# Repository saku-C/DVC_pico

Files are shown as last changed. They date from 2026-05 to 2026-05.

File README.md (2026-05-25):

# DVC-PICO v2 Controller & Analyzer

RP2040（Raspberry Pi Pico / Pico 2）をベースにした、多機能なDMX-512コントローラーおよびオシロスコープ・アナライザープロジェクトです。
ハードウェア（KiCad設計データ）とファームウェア（Arduinoスケッチ）が一体となって管理されています。

内部構造
https://qiita.com/kurumi18891/private/b40f511b77fc0b5f25af

操作マニュアル
https://qiita.com/kurumi18891/private/ef590465823563e47984

---

## 📂 フォルダ構成

```
DVC_pico2_1/ (リポジトリルート)
├── DVC_pico2_1.ino        # メインファームウェア (Arduinoスケッチ)
├── .gitignore             # Git除外設定ファイル
├── README.md              # 本ドキュメント
├── antigra_DVCpico/       # 補助フォルダ
└── kicad_DVC_pico/        # ハードウェア設計データ
    └── DVC-picov2/        # KiCad v2 回路図・基板アートワーク
        ├── DVC-picov2.kicad_pcb # 基板レイアウト
        ├── DVC-picov2.kicad_pro # KiCad プロジェクトファイル
        ├── DVC-picov2.kicad_sch # 回路図
        └── ...
```

---

## ✨ 主な機能

1. **多彩な通信モード（6チャネル拡張）**
   * **Monitor Only**: 送受信データの監視
   * **Read DMX -> SD**: 受信したDMXデータをCSV形式でSDカードにリアルタイム録画
   * **Write DMX <- SD**: SDカードに記録されたCSVファイルを再生し、DMX信号を出力
   * **Read DMX -> USB**: DMXデータをUSBシリアル経由でPCに送信
   * **Write DMX <- USB**: USB経由で受信したコマンドに基づいてDMX信号を出力
   * **Manual Controller**: 7つの操作キーを使用した、手動でのDMXチャンネル出力制御
2. **5つの画面表示モード**
   * **Waveform Monitor**: DMX各チャネルの値を波形（オシロスコープスタイル）でビジュアル表示
   * **Table Monitor**: DMX 512チャネルの数値をグリッド状に一覧表示
   * **Dashboard**: システムの稼働ステータスや通信統計、診断結果をサマリー表示
   * **Fixture Inspector**: 灯体（フィクスチャ）のチャンネル定義と設定値の確認
   * **Multi-Light Monitor**: 10灯のインテリジェントライトの個別モニターおよびプロファイル調整
3. **対話型フィクスチャ（灯体）エディター**
   * 接続されたDMX機器のチャンネル数や各チャンネルの役割（Dimmer, Red, Green, Blue, Strobe等）を本体キーで自由に変更・カスタム可能
4. **永続データ保存（EEPROMエミュレーション）**
   * 設定したフィクスチャのプロファイルデータをRP2040の内蔵フラッシュメモリに自動で保存・復元

---

## 🛠️ ハードウェア仕様とピン配置

### 主要コンポーネント
* **MCU**: Raspberry Pi Pico / Pico 2 (RP2040 / RP2350)
* **ディスプレイ**: 1.8インチ ST7735 TFTカラー液晶 (160x128)
* **外部ストレージ**: MicroSDカードスロット（ソフトウェアSPI動作）
* **DMXインターフェース**: MAX485トランシーバー搭載

### ピン割り当て (RP2040)
* **TFT ディスプレイ**:
  * `CS`  -> GPIO 22
  * `RST` -> GPIO 21
  * `DC`  -> GPIO 20
  * `LED` -> GPIO 17
* **SDカード (SoftSPI)**:
  * `SCK`  -> GPIO 10
  * `MISO` -> GPIO 11
  * `MOSI` -> GPIO 12
  * `CS`   -> GPIO 13
* **DMX**:
  * `TX`    -> GPIO 0
  * `RX`    -> GPIO 1
  * `RE_DE` -> GPIO 2
* **操作ボタン (Active LOW)**:
  * `SETTING` -> GPIO 9
  * `UP`      -> GPIO 8
  * `DOWN`    -> GPIO 4
  * `LEFT`    -> GPIO 6
  * `RIGHT`   -> GPIO 7
  * `ENTER`   -> GPIO 5
  * `BACK`    -> GPIO 3

---

## ⚙️ 開発環境と依存ライブラリ

ファームウェアをコンパイルするには、Arduino IDEに以下のライブラリを追加してください：

* **Adafruit_GFX** (ディスプレイ描画用)
* **Adafruit_ST7735** (ST7735制御用)
* **SdFat** (SDカードの高速読み書き用)
* **Pico DMX (DmxInput / DmxOutput)** (Earle Philhower版コアのDMX送受信サポート)

*※ボードマネージャーは「Raspberry Pi Pico/RP2040 (Earle Philhower版)」の使用を想定しています。*

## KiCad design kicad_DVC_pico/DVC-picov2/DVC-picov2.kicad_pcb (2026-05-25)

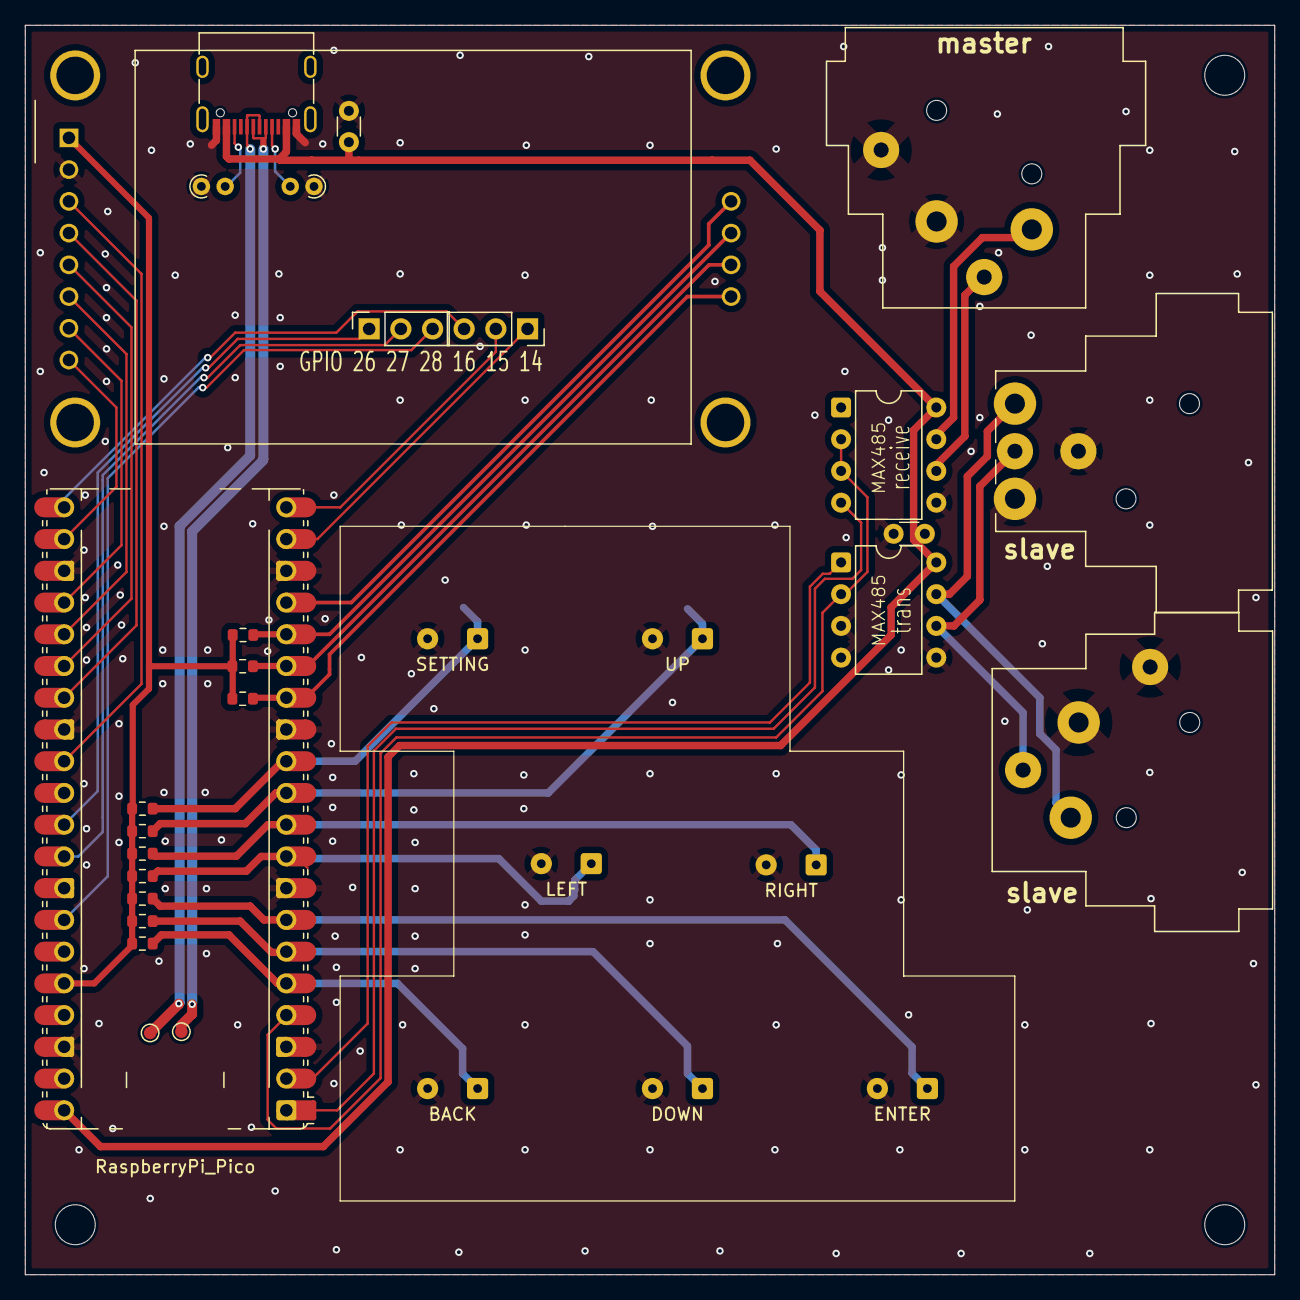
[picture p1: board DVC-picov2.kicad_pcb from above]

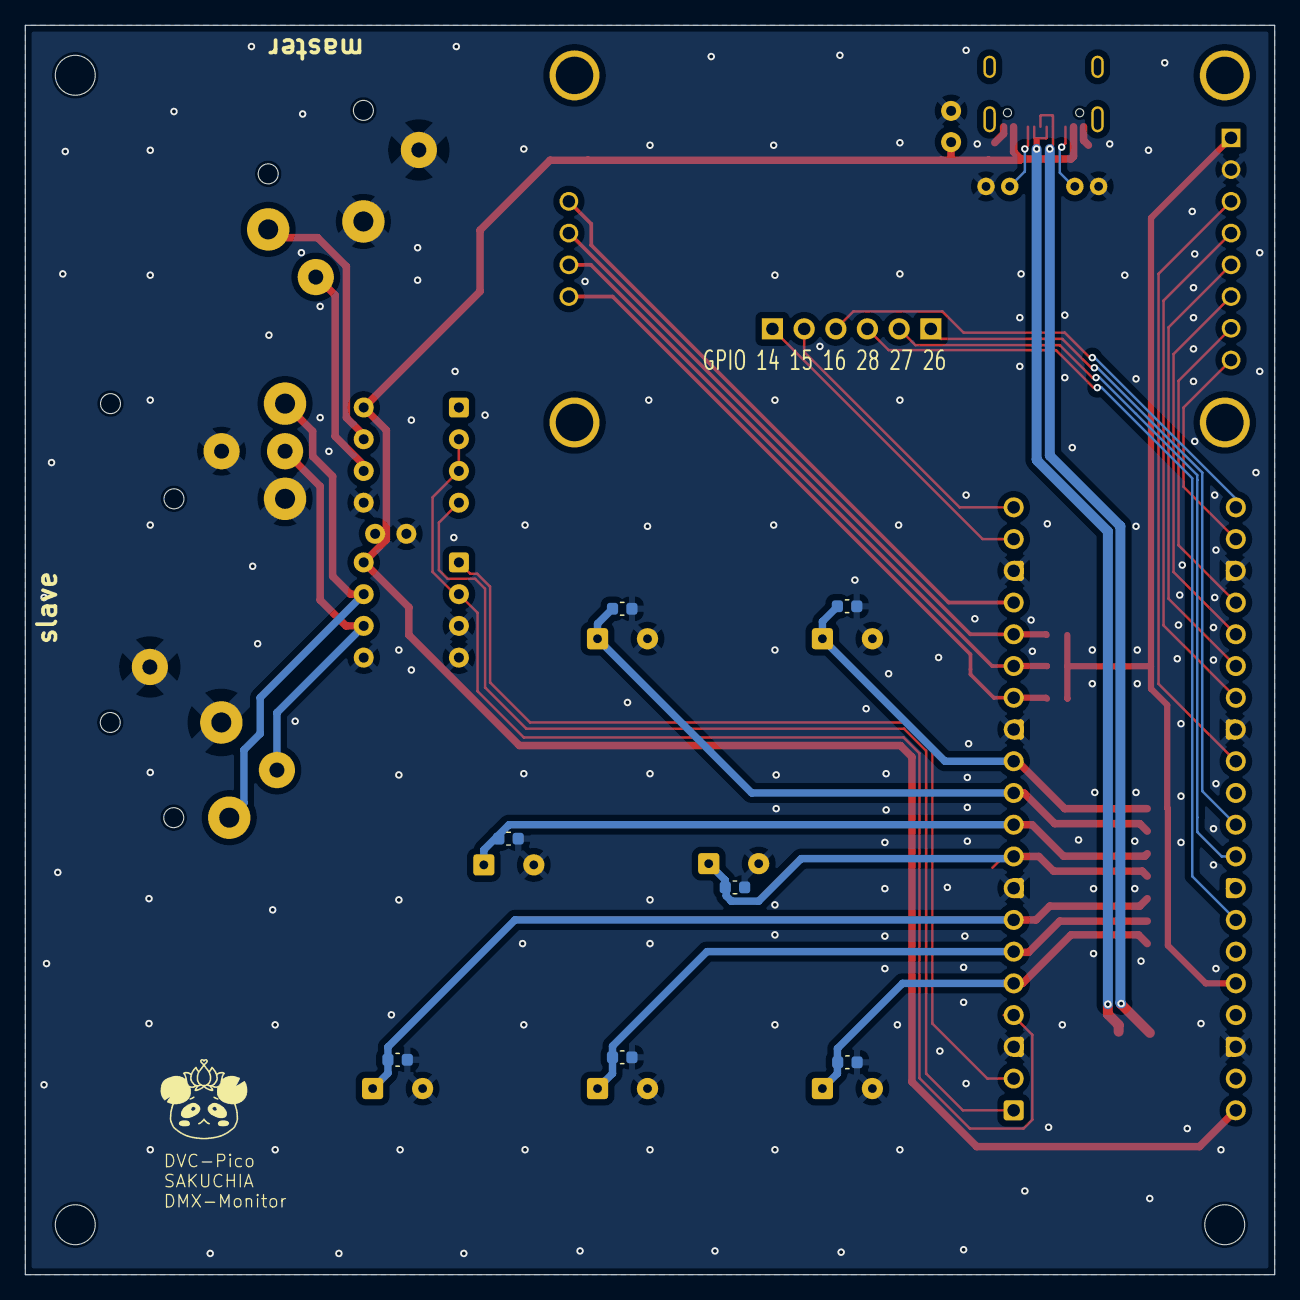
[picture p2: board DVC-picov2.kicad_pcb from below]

Board: 2 copper layers, 100.0 x 100.0 mm, 41 parts (7 on the bottom side), 37 nets.

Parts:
A1: RaspberryPi_Pico; RaspberryPi_Pico_Common_Unspecified
BACK: SW_Push; SolderWire-0.15sqmm_1x02_P4mm_D0.5mm_OD1.5mm
C1, C2: C; C_Disc_D3.0mm_W1.6mm_P2.50mm
C3, C4, C5, C6, C7, C8, C9: C; C_0603_1608Metric
DOWN: SW_Push; SolderWire-0.15sqmm_1x02_P4mm_D0.5mm_OD1.5mm
ENTER: SW_Push; SolderWire-0.15sqmm_1x02_P4mm_D0.5mm_OD1.5mm
H2, H3, H4: MountingHole; MountingHole_3.2mm_M3
J1: USB_C_Receptacle_USB2.0_16P; USB_C_Receptacle_G-Switch_GT-USB-7010ASV
J2, J3: XLR3_Ground; Jack_XLR_Neutrik_NC3FAH2-0_Horizontal
J4: XLR3_Ground; Jack_XLR_Neutrik_NC3MAH_Horizontal
J5, J6: Conn_01x03_Pin; PinSocket_1x03_P2.54mm_Vertical
LEFT: SW_Push; SolderWire-0.15sqmm_1x02_P4mm_D0.5mm_OD1.5mm
R1, R2: 5.1k; R_Axial_DIN0204_L3.6mm_D1.6mm_P1.90mm_Vertical
R3, R4, R5, R6, R7, R8, R9, R10, R11, R12: R; R_0603_1608Metric
RIGHT: SW_Push; SolderWire-0.15sqmm_1x02_P4mm_D0.5mm_OD1.5mm
SETTING: SW_Push; SolderWire-0.15sqmm_1x02_P4mm_D0.5mm_OD1.5mm
U1, U2: MAX485E; DIP-8_W7.62mm
U3: 1.8_TFT_SPI_128*160; 1.8_TFT_SPI_128_160_footprint
UP: SW_Push; SolderWire-0.15sqmm_1x02_P4mm_D0.5mm_OD1.5mm

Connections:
+3.3V: A1.36 (3V3), R3.1, R4.1, R5.1, R6.1, R7.1, R8.1, R9.1, R10.1, R11.1, R12.1, U3.1 (VCC)
A0: A1.26 (GPIO20), U3.5 (D/~C)
BTN_BACK: A1.5 (GPIO3), BACK.1, C3.1, R9.2
BTN_DOWN: A1.6 (GPIO4), C7.1, DOWN.1, R5.2
BTN_ENTER: A1.7 (GPIO5), C4.1, ENTER.1, R8.2
BTN_LEFT: A1.9 (GPIO6), C6.1, LEFT.1, R6.2
BTN_RIGHT: A1.10 (GPIO7), C5.1, R7.2, RIGHT.1
BTN_SETTING: A1.12 (GPIO9), C9.1, R3.2, SETTING.1
BTN_UP: A1.11 (GPIO8), C8.1, R4.2, UP.1
D+: J1.A6 (D+), J1.B6 (D+)
D-: J1.A7 (D-), J1.B7 (D-)
DMX_RX: A1.2 (GPIO1), U1.1 (RO)
DMX_TX: A1.1 (GPIO0), U2.4 (DI)
DMX_master_D+: J3.3, U2.6 (A)
DMX_master_D-: J3.2, U2.7 (B)
DMX_slave_D+: J2.3, J4.3, U1.6 (A)
DMX_slave_D-: J2.2, J4.2, U1.7 (B)
GND: A1.3 (GND), A1.8 (GND), A1.13 (GND), A1.18 (GND), A1.23 (GND), A1.28 (GND), A1.38 (GND), BACK.2, C1.2, C2.2, C3.2, C4.2, C5.2, C6.2, C7.2, C8.2, C9.2, DOWN.2, ENTER.2, J1.A1 (GND), J1.A12 (GND), J1.B1 (GND), J1.B12 (GND), J2.1, J2.G, J3.1, J3.G, J4.1, J4.G, LEFT.2, R1.1, R2.1, RIGHT.2, SETTING.2, U1.3 (DE), U1.4 (DI), U1.5 (GND), U2.5 (GND), U3.2 (GND), UP.2
GPIO14: A1.19 (GPIO14), J5.1
GPIO15: A1.20 (GPIO15), J5.2
GPIO16: A1.21 (GPIO16), J5.3
GPIO26: A1.31 (GPIO26_ADC0), J6.1
GPIO27: A1.32 (GPIO27_ADC1), J6.2
GPIO28: A1.34 (GPIO28_ADC2), J6.3
LED: A1.22 (GPIO17), U3.8 (LED)
MAX485_RE_DE: A1.4 (GPIO2), U1.2 (~RE), U2.2 (~RE), U2.3 (DE)
unnamed: J1.A5 (CC1), R2.2
unnamed: J1.B5 (CC2), R1.2
RESET: A1.27 (GPIO21), U3.4 (RESET)
SCK: A1.24 (GPIO18), U3.7 (SCK)
SDA: A1.25 (GPIO19), U3.6 (MOSI)
SD_CS: A1.17 (GPIO13), U3.9 (SD_CS)
SD_MISO: A1.15 (GPIO11), R11.2, U3.11 (SD_MISO)
SD_MOSI: A1.16 (GPIO12), R12.2, U3.10 (SD_MOSI)
SD_SCK: A1.14 (GPIO10), R10.2, U3.12 (SD_SCK)
VBUS: A1.40 (VBUS), C1.1, C2.1, J1.A4 (VBUS), J1.A9 (VBUS), J1.B4 (VBUS), J1.B9 (VBUS), U1.8 (VCC), U2.8 (VCC)
^cs: A1.29 (GPIO22), U3.3 (~CS)

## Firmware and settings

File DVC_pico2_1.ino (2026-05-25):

#include <Adafruit_GFX.h>
#include <Adafruit_ST7735.h>
#include <SPI.h>
#include <SdFat.h> // SD.h の代わりに SdFat.h を使用
typedef FsFile File; // Earle Philhower版コアのFS.h衝突回避用エイリアス
#include <EEPROM.h>  // ★EEPROMエミュレーション保存用
#include <DmxInput.h>
#include <DmxOutput.h>

void updateFileList();
// --- ピン定義 ---
  #define TFT_CS    22
  #define TFT_RST   21
  #define TFT_DC    20
  #define TFT_LED   17

  #define SD_SCK  10
  #define SD_MISO 11 // 回路図実態に合わせてアサイン
  #define SD_MOSI 12 // 回路図実態に合わせてアサイン
  #define SD_CS   13

// --- ソフトウェアSPIオブジェクトの定義 ---
SoftSpiDriver<SD_MISO, SD_MOSI, SD_SCK> softSpi;
SdFat SD;

  #define MAX485_RE_DE  2

  #define DMX_TX_PIN 0
  #define DMX_RX_PIN 1

  #define BTN_SETTING 9
  #define BTN_UP      8
  #define BTN_DOWN    4
  #define BTN_LEFT    6
  #define BTN_RIGHT   7
  #define BTN_ENTER   5
  #define BTN_BACK    3

  #define SWITCH_QUANTITY 7
//

// 閾値の定義 (単位を「ミリ秒」としてそのまま使います)
const uint16_t shortswt = 50;  // 短押し判定 (80ms)
const uint16_t longswt  = 1000; // 長押し判定 (1秒)

class SWITCH {
  public:
  uint8_t  pin;
  uint8_t  state; // 外から読み取る状態 (0:なし, 1:短押し, 2:長押し)
  uint8_t  step;  // クラス内部での進行状態記憶 (0:待機, 1:短押し処理済, 2:長押し処理済)
  
  uint32_t pressStartTime;   // 押され始めた時刻を記録
  uint32_t releaseStartTime; // 離され始めた時刻を記録
  bool     isPressed;        // 現在論理的に「押されている」と認識しているか

  SWITCH(int PIN) { 
    pin = PIN; 
    state = 0; 
    step = 0; 
    pressStartTime = 0;
    releaseStartTime = 0;
    isPressed = false;
  }
  SWITCH() {
    pin = 0; 
    state = 0; 
    step = 0; 
    pressStartTime = 0;
    releaseStartTime = 0;
    isPressed = false;
  }

  void Task() {
    // 現在の物理的なピンの状態を読み取る (LOWなら押されている)
    bool currentPhysicalState = (digitalRead(pin) == LOW);

    if (currentPhysicalState) {
      // --- ボタンが物理的に押されている場合 ---
      if (!isPressed) {
        // さっきまで離されていて、今まさに押された瞬間
        isPressed = true;
        pressStartTime = millis(); // 計測開始！
      } else {
        // 継続して押されている場合、経過時間を計算
        uint32_t pressDuration = millis() - pressStartTime;

        // 長押しの判定
        if (pressDuration > longswt) {
          if (step == 1) { // 短押し状態からのみ移行
            state = 2; // イベント発火
            step = 2;  // 発火済みマーク
          }
        } 
        // 短押しの判定
        else if (pressDuration > shortswt) {
          if (step == 0) { // 待機状態からのみ移行
            state = 1; // イベント発火
            step = 1;  // 発火済みマーク
          }
        }
      }
    } else {
      // --- ボタンが物理的に離されている場合 ---
      if (isPressed) {
        // さっきまで押されていて、今まさに離された瞬間
        isPressed = false;
        releaseStartTime = millis(); // 離された時刻を記録
      } else {
        // 継続して離されている場合
        // チャタリング（接点の微細な振動）対策として、
        // 「完全に離れてから50ミリ秒経過」するまではリセットしない
        if (step > 0 && (millis() - releaseStartTime > 50)) {
          state = 0;
          step = 0; // ここで初めてロック解除
        }
      }
    }
  }
};
SWITCH swt[SWITCH_QUANTITY] = {BTN_SETTING, BTN_UP, BTN_DOWN, BTN_LEFT, BTN_RIGHT, BTN_ENTER, BTN_BACK};

/* タイマー割り込み */
  struct repeating_timer st_timer;
  bool timer_flag = false;
//

bool Timer(struct repeating_timer *t) {
  timer_flag = true;
  return true;
}

//display class
  Adafruit_ST7735 tft = Adafruit_ST7735(TFT_CS, TFT_DC, TFT_RST);
  GFXcanvas16 canvas = GFXcanvas16(160, 128);
  DmxOutput dmxOut;
  DmxInput dmxIn;
//

// --- SDカード操作用のグローバル変数
  File targetFile;
  bool isFileOpened = false;
  uint32_t lastFlushTime = 0;
  bool isSdInitialized = false;  // ★追加: SDカードが正しく初期化されているか
  bool sdErrorWarning = false;   // ★追加: SD未検出時の警告フラグ
//

// --- SDカード再生 (Write SD) 用のグローバル変数 ---
  File playbackFile;
  bool isPlaybackFileOpened = false;
  uint32_t playbackStartTime = 0;   // 再生を開始した実時間(millis)
  uint32_t firstFrameTimestamp = 0; // ファイルの1行目に記録されていたタイムスタンプ
  uint32_t nextFrameTimestamp = 0;  // 次に再生する行のタイムスタンプ
  char sdLineBuf[2048];             // 1行分の読み込みバッファ
  bool isNextFrameReady = false;    // 次のフレームがメモリ上に待機しているか
//

// --- DMXdetaの共有変数---
  volatile uint8_t dmxData[512]; 
  volatile bool requestDraw = true; // 画面の再描画要求フラグ
  volatile int menuCursor = 0;      // メニューのカーソル位置
//

// --- processWriteUSB用のグローバル変数 ---
  const int USB_RX_BUF_SIZE = 2048; // 圧縮CSVの1行分を余裕で格納できるサイズ
  char usbRxBuf[USB_RX_BUF_SIZE];
  int usbRxIdx = 0;
//

// SD Core 1(TFT側)に渡すファイル名リストのバッファ
  char fileList[5][32]; 
  volatile int fileCount = 0;
  // 確定したファイル名を保持するバッファ
  char selectedFileName[32];
//

void generateNewFileName(char* dest) {
  int index = 0;
  char nameBuf[32];
  while (index < 1000) {
    sprintf(nameBuf, "rec_%03d.csv", index);
    if (!SD.exists(nameBuf)) {
      strncpy(dest, nameBuf, 31);
      dest[31] = '\0';
      return;
    }
    index++;
  }
  strncpy(dest, "rec_new.csv", 31);
  dest[31] = '\0';
}


// システムの進行状態
enum SystemState {
  SETTING_COMM, // 通信方法を選んでいる状態
  SETTING_DISP, // 表示方法を選んでいる状態
  SETTING_FILE, // ファイル設定
  RUNNING,      // 実際の処理を実行中の状態
  EDITING_FIXTURE // ★追加: 対話型 Fixture エディター状態
};
volatile SystemState sysState = SETTING_COMM;
volatile bool isCommunicationActive = false;

// 通信モード (6択に拡張)
enum CommMode {
  COMM_NONE,          // 1. Monitor Only
  COMM_READ_SD,       // 2. Read  DMX -> SD
  COMM_WRITE_SD,      // 3. Write DMX <- SD
  COMM_READ_USB,      // 4. Read  DMX -> USB
  COMM_WRITE_USB,     // 5. Write DMX <- USB
  COMM_MANUAL_WRITE   // 6. Manual Controller
};
volatile CommMode currentCommMode = COMM_NONE;

// --- マニュアルコントローラー用のグローバル変数 ---
volatile int manualSelectedCh = 0;      // 0〜511 (DMX CH 1〜512)
volatile bool manualDrawReset = true;   // 画面遷移クリアフラグ
volatile int waveformCursor = 0;        // ★追加: Waveform Monitor 拡大表示時のカーソル位置 (0〜127)

// 表示モード
enum DispMode {
  DISP_WAVEFORM,       // ★波形・オシロスコープモニター (旧DISP_VISUAL)
  DISP_TABLE,          // 数値テーブルモニター
  DISP_DASHBOARD,      // ★システム統計＆診断ダッシュボード (旧DISP_EMULATOR)
  DISP_FIXTURE,        // Fixture定義インスペクター
  DISP_MULTI_LIGHT     // 10灯マルチライトモニター
};
volatile DispMode currentDispMode = DISP_WAVEFORM;

enum LightType {
  TYPE_PAR,
  TYPE_LINEAR,
  TYPE_USER
};

enum ChMode{
  DIMMER,
  RED,
  BLUE,
  GREEN,
  CORER_WHEEL,
  WHILE,
  BEAM,
  MOVE_X,
  MOVE_Y,
  STROBE,       // ★追加
  CUSTOM_COLOR, // ★追加
  NO_SET
};

class LIGHT_SET{
  public:
  ChMode ch[16];
  int ChLength=8;//読むバイト長
  int farstCh=1;
  char LightName [32]="user defined";
  LightType type=TYPE_USER; // ★追加

  public:
  LIGHT_SET(ChMode CH[],int CHLENGTH,int FARSTCH,const char* LIGHTNAME, LightType TYPE = TYPE_USER){
    farstCh=FARSTCH;
    ChLength = (CHLENGTH > 16) ? 16 : CHLENGTH; 
    for (int i = 0; i < ChLength; i++) {
      ch[i] = CH[i];
    }
    for (int i = ChLength; i < 16; i++) {
      ch[i] = NO_SET;
    }
    int j = 0;
    while (j < 31 && LIGHTNAME[j] != '\0') {
      LightName[j] = LIGHTNAME[j];
      j++;
    }
    LightName[j] = '\0'; // 最後に必ず終端文字を入れる
    type = TYPE;
  }
  LIGHT_SET(){
    farstCh = 1;
    ChLength = 8;
    for(int i=0; i<16; i++) ch[i] = NO_SET;
    type = TYPE_USER;
    strcpy(LightName, "user defined");
  }

  void setType(LightType t, int startCh, const char* name) {
    farstCh = startCh;
    type = t;
    strncpy(LightName, name, 31);
    LightName[31] = '\0';
    if (t == TYPE_PAR) {
      ChLength = 7;
      ch[0] = DIMMER;
      ch[1] = RED;
      ch[2] = GREEN;
      ch[3] = BLUE;
      ch[4] = STROBE;
      ch[5] = NO_SET;
      ch[6] = NO_SET;
      for (int i = 7; i < 16; i++) ch[i] = NO_SET;
    } else if (t == TYPE_LINEAR) {
      ChLength = 8;
      ch[0] = DIMMER;
      ch[1] = STROBE;
      ch[2] = RED;
      ch[3] = GREEN;
      ch[4] = BLUE;
      ch[5] = WHILE;
      ch[6] = CUSTOM_COLOR;
      ch[7] = NO_SET;
      for (int i = 8; i < 16; i++) ch[i] = NO_SET;
    } else { // TYPE_USER
      ChLength = 8;
      ch[0] = DIMMER;
      ch[1] = RED;
      ch[2] = GREEN;
      ch[3] = BLUE;
      ch[4] = WHILE;
      ch[5] = STROBE;
      ch[6] = NO_SET;
      ch[7] = NO_SET;
      for (int i = 8; i < 16; i++) ch[i] = NO_SET;
    }
  }
};

// --- 10灯設定の共有配列化 ＆ スクロール管理 ---
LIGHT_SET lightSets[10];
volatile int selectedLightSetIdx = 0; // 現在フォーカスしているライトセット (0〜9)
volatile int scrollOffset = 0;        // スクロール開始インデックス (0〜6)
volatile int editChCursor = 0;        // 編集中のチャンネル・項目インデックス
volatile int fixturePage = 0;         // ★追加: Fixture Inspector の現在表示ページ (0 or 1)

// --- Fixture Inspector 用のヘルパー関数 ---
const char* getChModeName(int mode) {
  switch((ChMode)mode) {
    case DIMMER:       return "Dimmer  ";
    case RED:          return "Red     ";
    case GREEN:        return "Green   ";
    case BLUE:         return "Blue    ";
    case CORER_WHEEL:  return "ColorWhl";
    case WHILE:        return "White   ";
    case BEAM:         return "Beam    ";
    case MOVE_X:       return "Pan     ";
    case MOVE_Y:       return "Tilt    ";
    case STROBE:       return "Strobe  ";
    case CUSTOM_COLOR: return "CustClr ";
    default:           return "None    ";
  }
}

// ★追加: EEPROMエミュレーションによる保存・復元関数
#define EEPROM_SIZE 2048 // 10灯分 (約1.08KB) を余裕をもって格納できるサイズ

bool saveFixturesToFlash() {
  EEPROM.begin(EEPROM_SIZE);
  EEPROM.put(0, lightSets);
  bool success = EEPROM.commit();
  EEPROM.end();
  if (success) {
    Serial.println("Saved fixtures to EEPROM successfully!");
  } else {
    Serial.println("EEPROM Error: commit failed.");
  }
  return success;
}

bool loadFixturesFromFlash() {
  EEPROM.begin(EEPROM_SIZE);
  LIGHT_SET tempSets[10];
  EEPROM.get(0, tempSets);
  EEPROM.end();

  // データの整合性チェック (各灯体のfarstChが正常範囲 1~512 にあるか)
  bool isValid = true;
  for (int i = 0; i < 10; i++) {
    if (tempSets[i].farstCh < 1 || tempSets[i].farstCh > 512 || tempSets[i].ChLength < 1 || tempSets[i].ChLength > 16) {
      isValid = false;
      break;
    }
  }

  if (isValid) {
    memcpy(lightSets, tempSets, sizeof(lightSets));
    Serial.println("Loaded fixtures from EEPROM successfully!");
    return true;
  } else {
    Serial.println("EEPROM empty or corrupted. Using defaults.");
    return false;
  }
}

// ★追加: SDカード初期化ヘルパー関数
bool initSDCard() {
  if (SD.begin(SdSpiConfig(SD_CS, DEDICATED_SPI, SD_SCK_MHZ(16), &softSpi))) {
    isSdInitialized = true;
    updateFileList();
    return true;
  }
  isSdInitialized = false;
  return false;
}

// =========================================================================
// 【Core 0】 通信・制御コア (ボタン判定, 状態遷移, DMX通信)
// =========================================================================
void setup() {
  Serial.begin(115200);

  // Core 0でSDカードを初期化 (ソフトウェアSPI構成)
  if (!initSDCard()) {
    Serial.println("SD initialization failed!");
  } else {
    Serial.println("SD initialization done (Software SPI).");
  }

  dmxOut.begin(DMX_TX_PIN);
  dmxIn.begin(DMX_RX_PIN, 1, 512);
  dmxIn.read_async((uint8_t*)dmxData);

  pinMode(MAX485_RE_DE, OUTPUT);
  digitalWrite(MAX485_RE_DE, LOW);

  pinMode(BTN_UP, INPUT_PULLUP);
  pinMode(BTN_DOWN, INPUT_PULLUP);
  pinMode(BTN_LEFT, INPUT_PULLUP);
  pinMode(BTN_RIGHT, INPUT_PULLUP);
  pinMode(BTN_ENTER, INPUT_PULLUP);
  pinMode(BTN_BACK, INPUT_PULLUP);
  pinMode(BTN_SETTING, INPUT_PULLUP);

  // --- デモ10ライトセットの初期配置 & ロード ---
  if (!loadFixturesFromFlash()) {
    // 読み込めない場合は初期設定を行い、保存する
    lightSets[0].setType(TYPE_PAR, 1, "Light Set 1");
    lightSets[1].setType(TYPE_LINEAR, 8, "Light Set 2");
    lightSets[2].setType(TYPE_PAR, 16, "Light Set 3");
    lightSets[3].setType(TYPE_USER, 24, "Light Set 4");
    lightSets[4].setType(TYPE_PAR, 32, "Light Set 5");
    lightSets[5].setType(TYPE_LINEAR, 39, "Light Set 6");
    lightSets[6].setType(TYPE_PAR, 47, "Light Set 7");
    lightSets[7].setType(TYPE_USER, 55, "Light Set 8");
    lightSets[8].setType(TYPE_PAR, 63, "Light Set 9");
    lightSets[9].setType(TYPE_LINEAR, 70, "Light Set 10");
    saveFixturesToFlash();
  }
}
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
void loop() {
  // 7つの物理スイッチの入力スキャン
  for (int i = 0; i < SWITCH_QUANTITY; i++) {
    swt[i].Task();
  }

  handleButtons();     // 物理ボタン入力のイベント判定と状態遷移
  handleAutoRepeat();  // ボタン長押し時の高速オートリピート処理
  handleSerialInput(); // PC（シリアル）からのキーボード入力を判定

  // ★追加: アドレス調整ボタン（LEFT/RIGHT）が離された瞬間のオートセーブ
  static bool lastChChangingPressed = false;
  bool isChChangingPressed = false;
  if (sysState == RUNNING && currentDispMode == DISP_MULTI_LIGHT) {
    isChChangingPressed = swt[3].isPressed || swt[4].isPressed;
  }
  if (!isChChangingPressed && lastChChangingPressed) {
    saveFixturesToFlash();
  }
  lastChChangingPressed = isChChangingPressed;

  // 通信モードに応じたDMXデータ入出力処理の実行
  if (isCommunicationActive) {
    if (currentCommMode == COMM_READ_USB) {
      processReadUSB();
    } else if (currentCommMode == COMM_READ_SD) {
      processReadSD();
    } else if (currentCommMode == COMM_WRITE_USB) {
      processWriteUSB();
    } else if (currentCommMode == COMM_WRITE_SD) {
      processWriteSD();
    } else if (currentCommMode == COMM_MANUAL_WRITE) {
      processManualWrite();
    }
  }

  delay(2); // Core 0のスレッド待機負荷調整
}

// =========================================================================
// 【Core 1】 描画専用コア (メニューUI, DMXモニター表示)
// =========================================================================
void setup1() {
  add_repeating_timer_us(33000, Timer, NULL, &st_timer);

  pinMode(TFT_LED, OUTPUT);
  digitalWrite(TFT_LED, HIGH);

  tft.initR(INITR_BLACKTAB);
  tft.setRotation(3);
  tft.fillScreen(ST77XX_BLACK);
  tft.setTextColor(ST77XX_WHITE);
  tft.setTextSize(1);
}

void loop1() {
  // システムの状態に応じた画面を描画
  if (timer_flag == true) {

    if (sysState == SETTING_COMM) {
      if (requestDraw) { drawCommMenu(); requestDraw = false; }
    } 
    else if (sysState == SETTING_DISP) {
      if (requestDraw) { drawDispMenu(); requestDraw = false; }
    } 
    else if (sysState == SETTING_FILE) {
      if (requestDraw) { drawSdFileList(); requestDraw = false; }
    }
    else if (sysState == EDITING_FIXTURE) {
      // エディター描画
      void drawFixtureEditor(); // 前方宣言
      drawFixtureEditor();
    }
    else if (sysState == RUNNING) {
      // ★追加・修正：モード移行時やページ切替時だけ画面全体をクリアする
      if (requestDraw) {
        if (currentCommMode != COMM_MANUAL_WRITE) {
          tft.fillScreen(ST77XX_BLACK);
        }
        requestDraw = false;
      }

      // 実行中は常に選ばれた表示モードの数値を上書き描画し続ける (リアルタイム更新)
      if (currentCommMode == COMM_MANUAL_WRITE) {
        void drawManualWrite(); // 前方宣言
        drawManualWrite();
      } else if (currentDispMode == DISP_WAVEFORM) {
        void drawMonitorWaveform(); // 前方宣言
        drawMonitorWaveform();
      } else if (currentDispMode == DISP_TABLE) {
        drawMonitorTable();
      } else if (currentDispMode == DISP_DASHBOARD) {
        void drawMonitorDashboard(); // 前方宣言
        drawMonitorDashboard();
      } else if (currentDispMode == DISP_FIXTURE) {
        drawMonitorFixture(); 
      } else if (currentDispMode == DISP_MULTI_LIGHT) {
        void drawMonitorMultiLight(); // 前方宣言
        drawMonitorMultiLight();
      }
    }

    timer_flag = false;
  }
}

// --- メニュー描画関数 ---
void drawCommMenu() {
  tft.fillScreen(ST77XX_BLACK);
  
  // Draw simple header
  tft.fillRect(0, 0, 160, 18, 0x2104); // Dark slate grey header bar
  tft.setTextColor(ST77XX_WHITE);
  tft.setTextSize(1);
  tft.setCursor(6, 5);
  tft.print("DVC PICO - MODE SELECT");
  
  // Draw separator line
  tft.drawFastHLine(0, 19, 160, 0x528A); // Slate grey separator line
  
  const char* items[] = {
    "1. Monitor Only",
    "2. Read  DMX -> SD",
    "3. Write DMX <- SD",
    "4. Read  DMX -> USB",
    "5. Write DMX <- USB",
    "6. Manual Controller"
  };
  
  for (int i = 0; i < 6; i++) {
    int y = 21 + (i * 15);
    if (i == menuCursor) {
      // Solid elegant Ice Blue button
      tft.fillRoundRect(4, y, 152, 13, 2, 0x05FF); 
      tft.setTextColor(ST77XX_BLACK);
    } else {
      // Subtle dark grey button border
      tft.drawRoundRect(4, y, 152, 13, 2, 0x2104); 
      tft.setTextColor(ST77XX_WHITE);
    }
    tft.setCursor(12, y + 3);
    tft.print(items[i]);
  }

  // ★追加: 警告または操作ガイドの表示
  if (sdErrorWarning) {
    tft.fillRect(4, 113, 152, 13, ST77XX_RED);
    tft.setTextColor(ST77XX_WHITE);
    tft.setCursor(14, 116);
    tft.print("ERR: SD CARD NOT READY");
  } else {
    tft.fillRect(4, 113, 152, 13, ST77XX_BLACK);
    tft.setTextColor(0x7BEF); // スレートグレー
    tft.setCursor(6, 116);
    tft.print("[ENT] SELECT [UP/DN] MOVE");
  }
}

void drawDispMenu() {
  tft.fillScreen(ST77XX_BLACK);
  
  // Draw header
  tft.fillRect(0, 0, 160, 18, 0x2104); // Dark slate grey
  tft.setTextColor(ST77XX_WHITE);
  tft.setTextSize(1);
  tft.setCursor(6, 5);
  tft.print("DVC PICO - DISPLAY SET");
  
  tft.drawFastHLine(0, 19, 160, 0x528A); // Slate grey separator line
  
  const char* items[] = {
    "1. Waveform Monitor",
    "2. Table Monitor",
    "3. System Dashboard",
    "4. Fixture Inspector",
    "5. Multi-Light Monitor"
  };
  
  for (int i = 0; i < 5; i++) {
    int y = 20 + (i * 19); // 5個表示するため間隔と高さを微調整
    if (i == menuCursor) {
      tft.fillRoundRect(4, y, 152, 15, 2, 0x05FF);
      tft.setTextColor(ST77XX_BLACK);
    } else {
      tft.drawRoundRect(4, y, 152, 15, 2, 0x2104);
      tft.setTextColor(ST77XX_WHITE);
    }
    tft.setCursor(10, y + 4);
    tft.print(items[i]);
  }
}

// --- モニター描画関数 ---
void drawMonitorWaveform() {
  canvas.fillScreen(ST77XX_BLACK);

  // 1. ヘッダー描画
  canvas.fillRect(0, 0, 160, 15, 0x2104); // ダークスレートグレーのヘッダーバー
  canvas.setTextColor(ST77XX_WHITE);
  canvas.setTextSize(1);
  canvas.setCursor(6, 4);
  
  if (menuCursor == 0) {
    canvas.print("WAVEFORM: CH 001 - 512 [ALL]");
  } else {
    int startCh = (menuCursor - 1) * 128 + 1;
    char headerBuf[32];
    sprintf(headerBuf, "WAVEFORM: CH %03d - %03d", startCh, startCh + 127);
    canvas.print(headerBuf);
  }
  canvas.drawFastHLine(0, 15, 160, 0x528A); // セパレーター

  int yBase = 110;
  int maxBarHeight = 80;

  if (menuCursor == 0) {
    // 全512ch表示モード (横160pxに圧縮表示、3.2ch/px)
    for (int i = 0; i < 160; i++) {
      int start = (i * 512) / 160;
      int end = ((i + 1) * 512) / 160;
      uint8_t maxVal = 0;
      for (int c = start; c < end; c++) {
        if (dmxData[c] > maxVal) maxVal = dmxData[c];
      }
      int barH = (maxVal * maxBarHeight) / 255;
      if (barH > 0) {
        canvas.drawFastVLine(i, yBase - barH, barH, 0x05FF); // アイスブルー
      }
    }
  } else {
    // 128ch拡大表示モード (X=16〜143、左右マージン16px、1ch=1px)
    int startCh = (menuCursor - 1) * 128;
    for (int i = 0; i < 128; i++) {
      int chIdx = startCh + i;
      uint8_t val = dmxData[chIdx];
      int barH = (val * maxBarHeight) / 255;
      bool isCursor = (i == waveformCursor);
      uint16_t color = isCursor ? ST77XX_WHITE : 0x05FF;
      if (barH > 0) {
        canvas.drawFastVLine(16 + i, yBase - barH, barH, color);
      }
      if (isCursor) {
        // カーソルインジケータ（バーの下に小さなドットまたは三角を描画）
        canvas.drawPixel(16 + i, yBase + 2, ST77XX_WHITE);
        canvas.drawPixel(16 + i - 1, yBase + 3, 0x528A);
        canvas.drawPixel(16 + i, yBase + 3, ST77XX_WHITE);
        canvas.drawPixel(16 + i + 1, yBase + 3, 0x528A);
      }
    }

    // 選択されたチャンネルと値の大きな数値表示 (Y=17〜25)
    int curCh = startCh + waveformCursor + 1;
    uint8_t curVal = dmxData[curCh - 1];
    
    // 背景の小さな黒枠でテキスト視認性を高める
    canvas.fillRect(4, 18, 152, 9, ST77XX_BLACK);
    canvas.setTextColor(ST77XX_WHITE);
    canvas.setCursor(6, 19);
    char infoBuf[32];
    sprintf(infoBuf, "CH: %03d  VALUE: %3d", curCh, curVal);
    canvas.print(infoBuf);
  }

  // 2. フッター描画 (操作ガイド)
  canvas.fillRect(0, 114, 160, 14, 0x2104); // ダークスレートグレーのフッターバー
  canvas.setTextColor(0x7BEF); // ライトグレー
  canvas.setCursor(6, 117);
  if (menuCursor == 0) {
    canvas.print("PAGE 1/5   [UP/DN] NAVI");
  } else {
    char footBuf[32];
    sprintf(footBuf, "PAGE %d/5   [UP/DN]P [LF/RT]CUR", menuCursor + 1);
    canvas.print(footBuf);
  }

  tft.drawRGBBitmap(0, 0, canvas.getBuffer(), 160, 128);
}
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
